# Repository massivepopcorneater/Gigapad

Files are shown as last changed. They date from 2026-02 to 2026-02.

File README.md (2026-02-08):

# Gigapad
A 9-key macropad that includes a LED for each key, a rotary encoder and a 0.91-inch OLED display. I made this project to challenge myself so that I can be better prepared to create real-world solutions and also I having a macropad with an OLED screen and a rotary encoder is pretty cool too. (Also for a soldering iron lol) 

Gigapad is a custom 9-key mechanical macropad built around the Seeed XIAO RP2040, featuring a rotary encoder and an OLED display.  
It is designed as a compact, programmable input device using QMK firmware, suitable for shortcuts, media control, and custom workflows.

---

## 🧱 Case & Assembly Fit

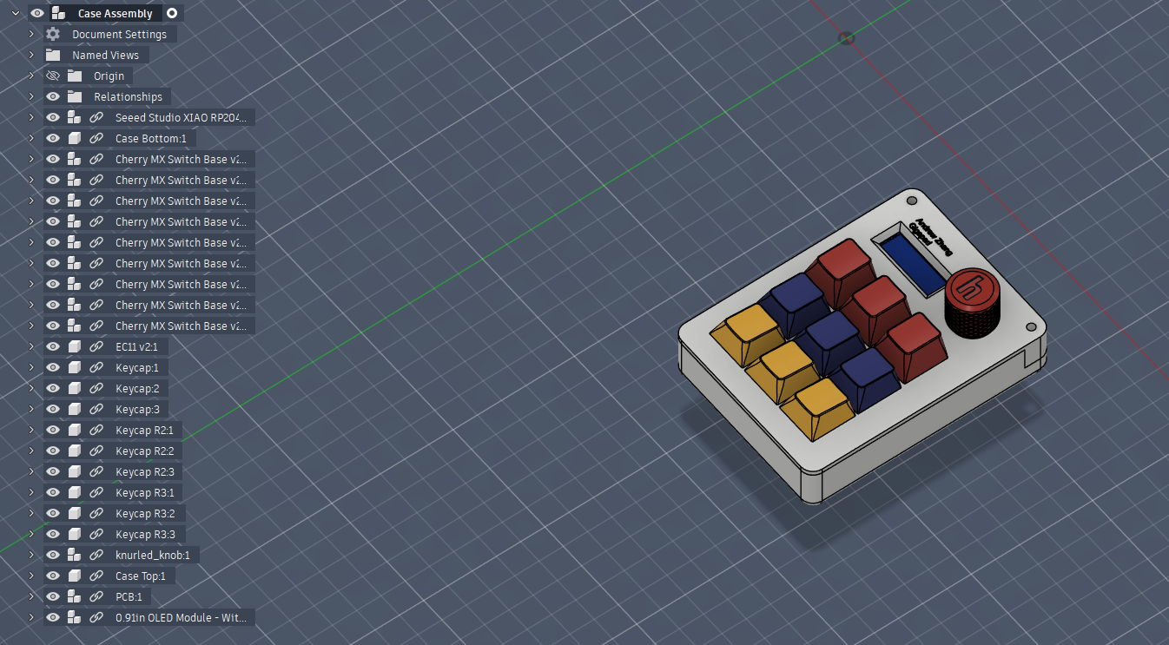
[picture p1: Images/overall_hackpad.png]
Overall Hackpad


Made using Fusion 360 

Features:
- Easy access to the USB-C port
- Secured PCB and case using 4 M3 Screws with brass heatsets (2 on the case, 2 on the case and pcb)
- Different key levels for a more ergonomic feel

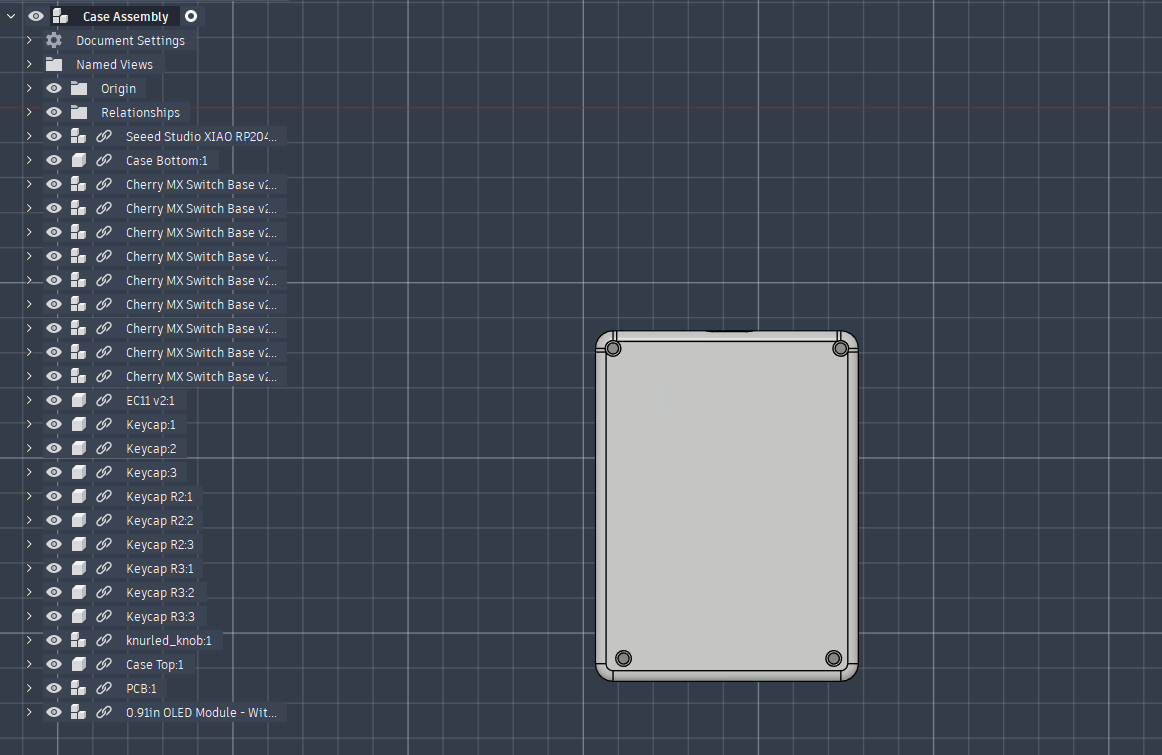
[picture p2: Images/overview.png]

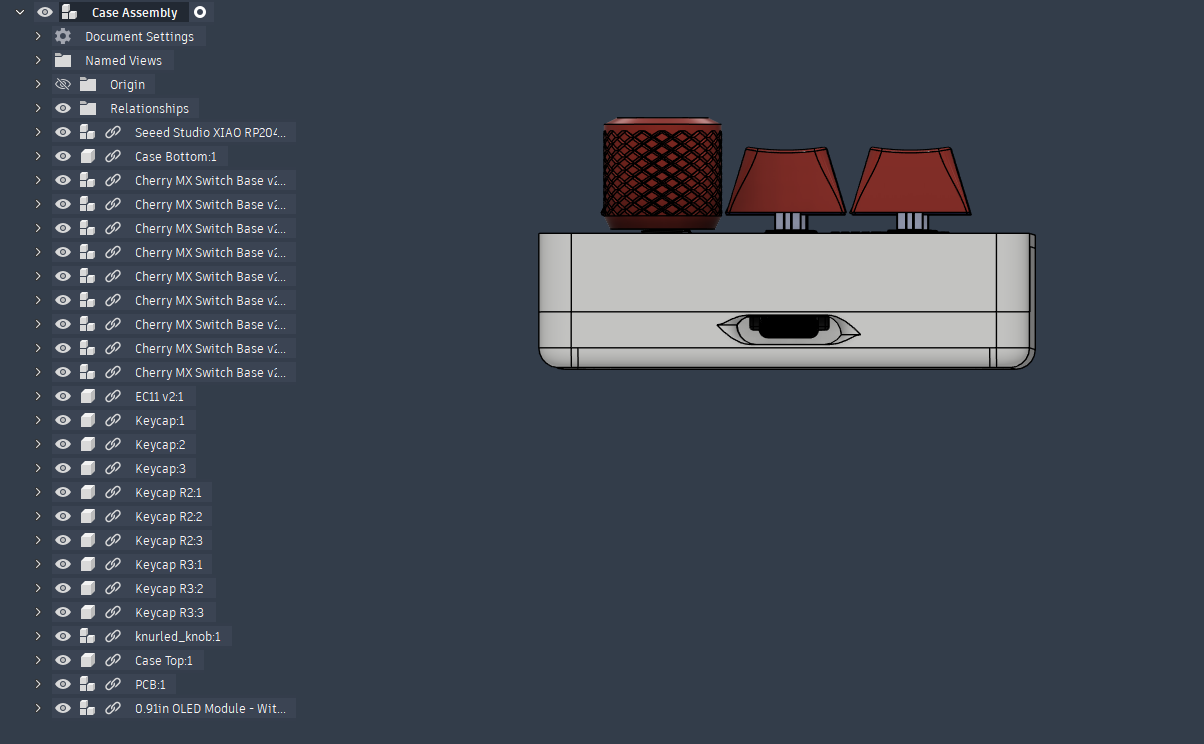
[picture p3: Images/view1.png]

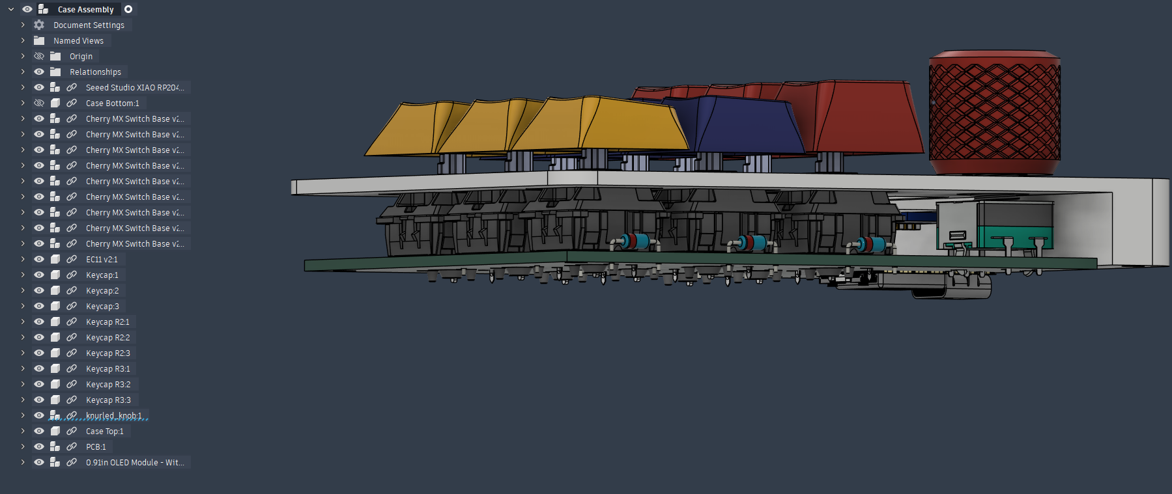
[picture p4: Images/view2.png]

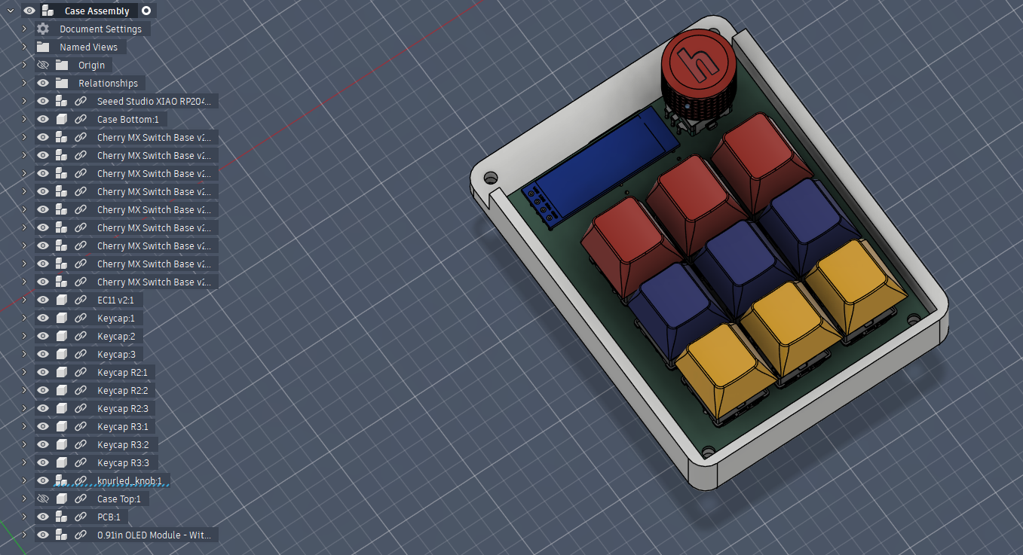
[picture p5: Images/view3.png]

  
---

## 📐 Schematic

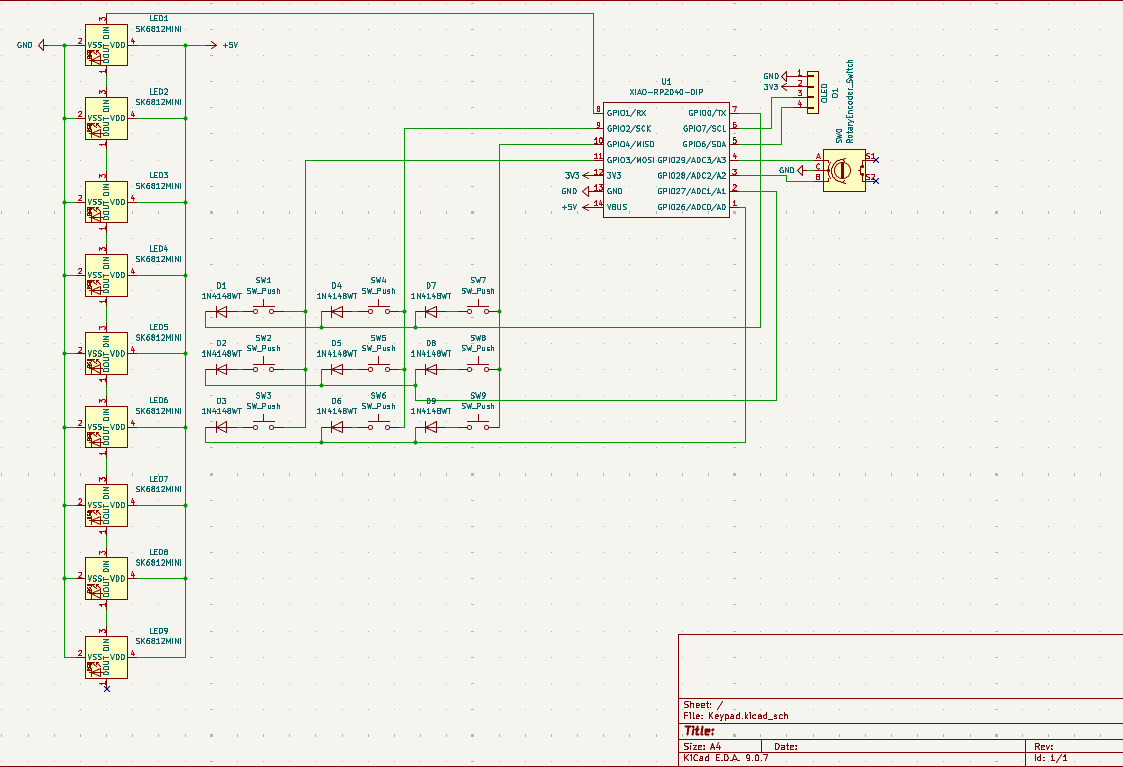
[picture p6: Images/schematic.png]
Schematic


Made Using KiCad

The schematic shows:
- A 3×3 key matrix 
- A rotary encoder connected directly to GPIO pins 
- An OLED display
- 9 Mini-LED in series delivered using parallel power

---

## 🧩 PCB

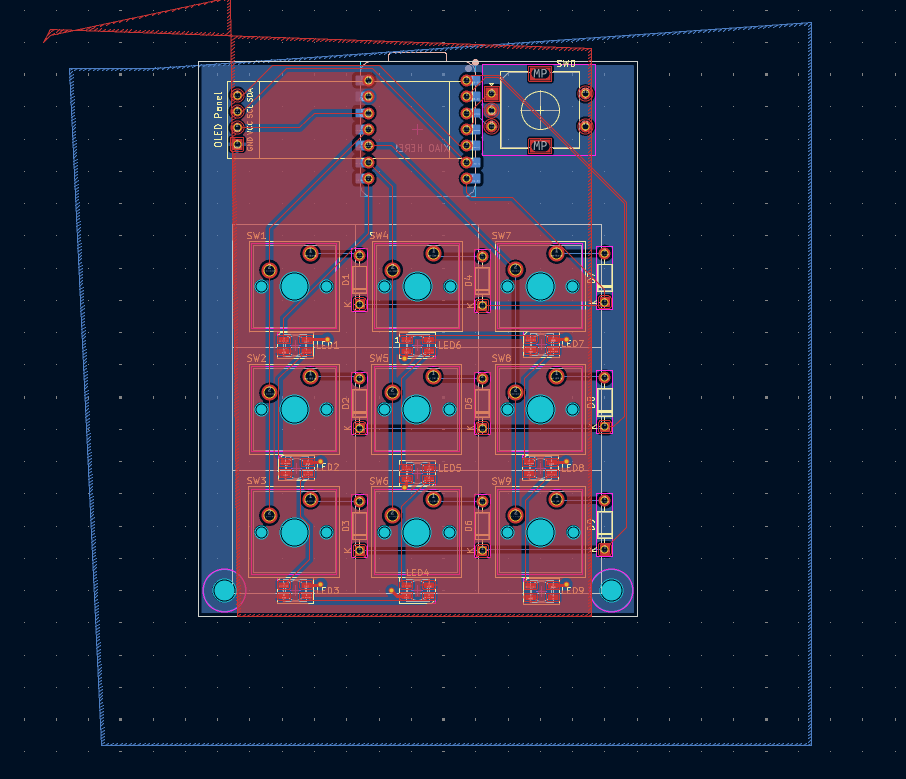
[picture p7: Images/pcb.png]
PCB


The PCB is a 2-layer board designed for JLCPCB manufacturing with:
- 1 oz copper
- Dedicated encoder pins
- Ground pours and 5V pour

---

## 🧾 Bill of Materials (BOM)

| Part | Quantity | Description |
|----|----|----|
| Microcontroller | 1x | Seeed XIAO RP2040 |
| Mechanical Switches | 9x | MX-style switches |
| Keycaps | 9x | ABS Keycaps |
| Rotary Encoder | 1x | EC11 |
| OLED Display | 1x | 0.91-inch OLED Display |
| Diodes | 9x | 1N4148  |
| Brass Heat-Set Inserts | 4x | M3 |
| Screws | 4x | M3 × 16 mm |
| PCB | 1x | Custom 2-layer PCB |
| Case | 1x | 3D-printed enclosure |

---

## 💻 Firmware

Gigapad runs **QMK firmware**, configured for:
- 3×3 key matrix
- Rotary encoder using dedicated GPIO pins
- OLED display output
- Fully customizable keymap

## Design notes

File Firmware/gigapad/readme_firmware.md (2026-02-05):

# gigapad

gigapad

*A short description of the keyboard/project*

* Keyboard Maintainer: [Andrew](https://github.com/massivepopcorneater)
* Hardware Supported: *The PCBs, controllers supported*
* Hardware Availability: *Links to where you can find this hardware*

Make example for this keyboard (after setting up your build environment):

    make gigapad:default

Flashing example for this keyboard:

    make gigapad:default:flash

See the [build environment setup](https://docs.qmk.fm/#/getting_started_build_tools) and the [make instructions](https://docs.qmk.fm/#/getting_started_make_guide) for more information. Brand new to QMK? Start with our [Complete Newbs Guide](https://docs.qmk.fm/#/newbs).

## Bootloader

Enter the bootloader in 3 ways:

* **Bootmagic reset**: Hold down the key at (0,0) in the matrix (usually the top left key or Escape) and plug in the keyboard
* **Physical reset button**: Briefly press the button on the back of the PCB - some may have pads you must short instead
* **Keycode in layout**: Press the key mapped to `QK_BOOT` if it is available

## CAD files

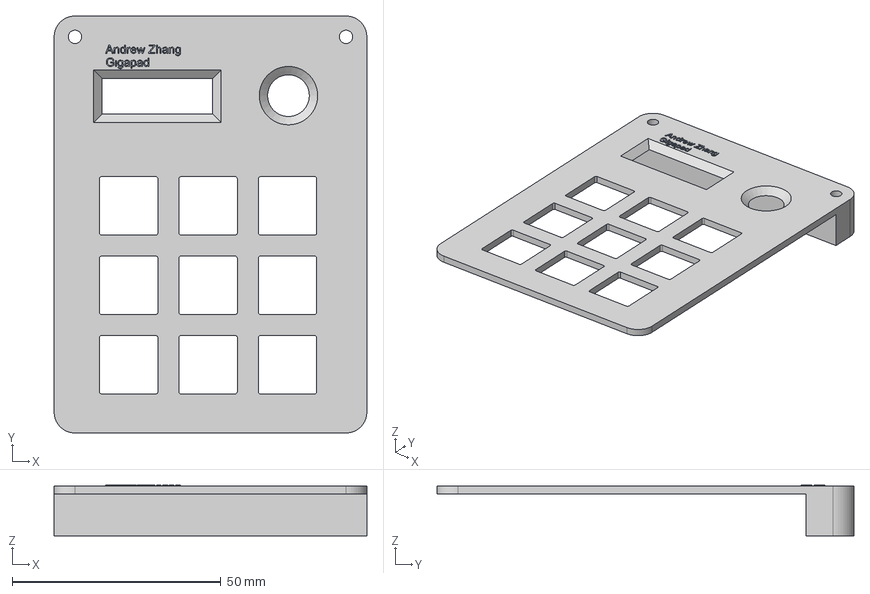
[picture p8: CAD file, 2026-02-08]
Case Design/Case Top.step
75.0 x 100.0 x 12.2 mm

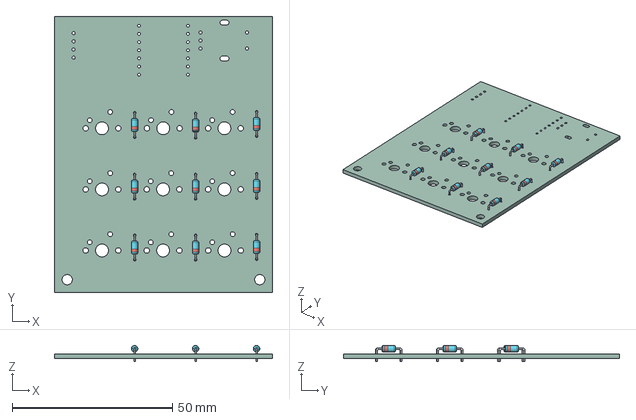
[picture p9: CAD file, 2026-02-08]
Production Files/PCB.step
68.0 x 86.0 x 5.01 mm
D_DO-35_SOD27_P7.62mm_Horizontal x 9
Keypad_PCB

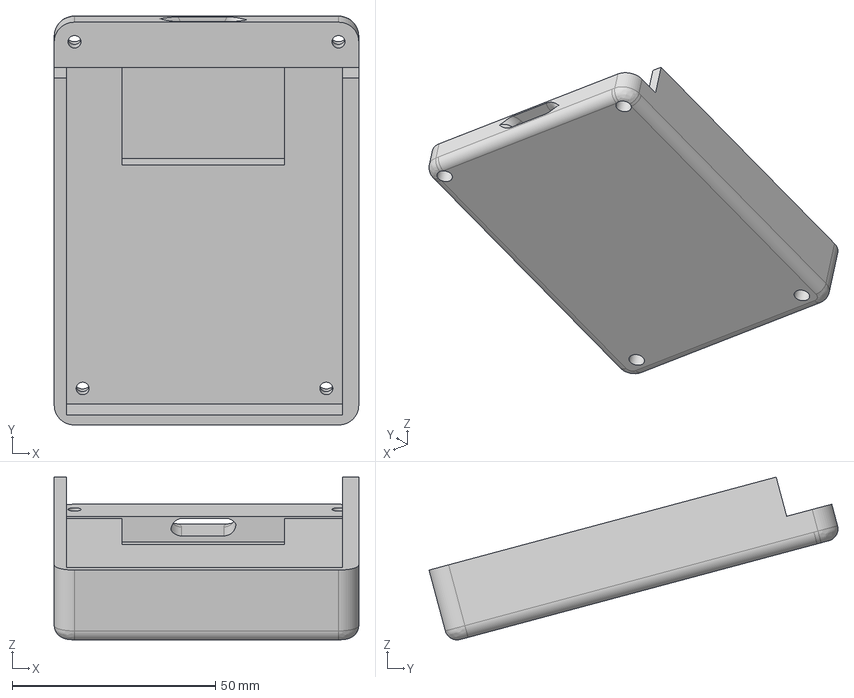
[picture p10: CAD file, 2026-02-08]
Case Design/Case Bottom.step
75.0 x 100.7 x 40.1 mm

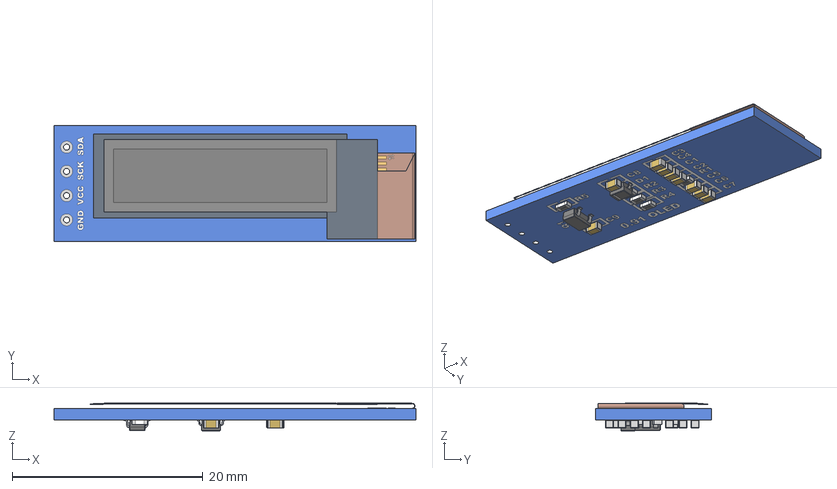
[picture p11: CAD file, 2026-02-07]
Case Design/0.91in OLED Module - Without Glass v1.step
37.9 x 12.1 x 2.93 mm

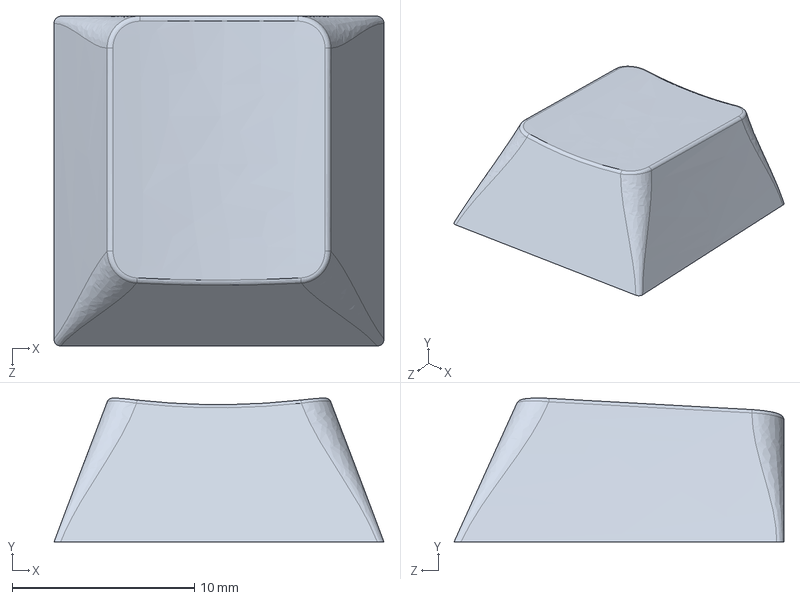
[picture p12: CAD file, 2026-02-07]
Production Files/r2_100.STEP
18.1 x 7.89 x 18.1 mm

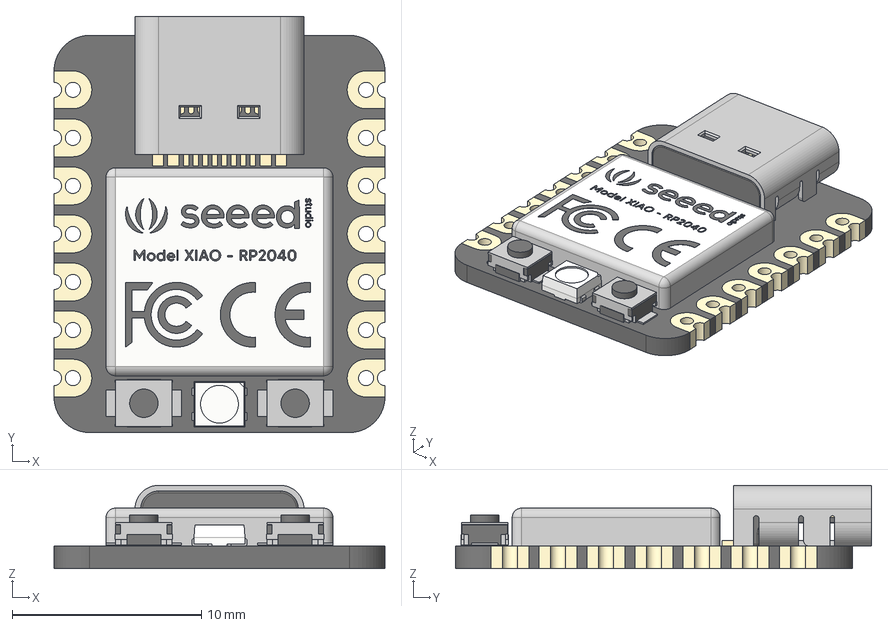
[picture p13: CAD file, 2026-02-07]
Case Design/Seeed Studio XIAO RP2040 v1.step
17.5 x 22.0 x 4.40 mm

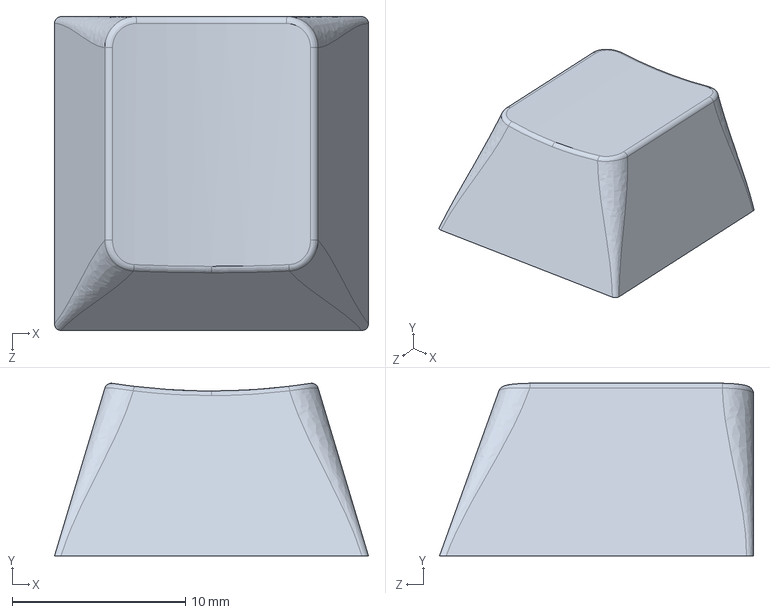
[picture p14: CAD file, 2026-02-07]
Production Files/r1_100.STEP
18.1 x 9.95 x 18.1 mm

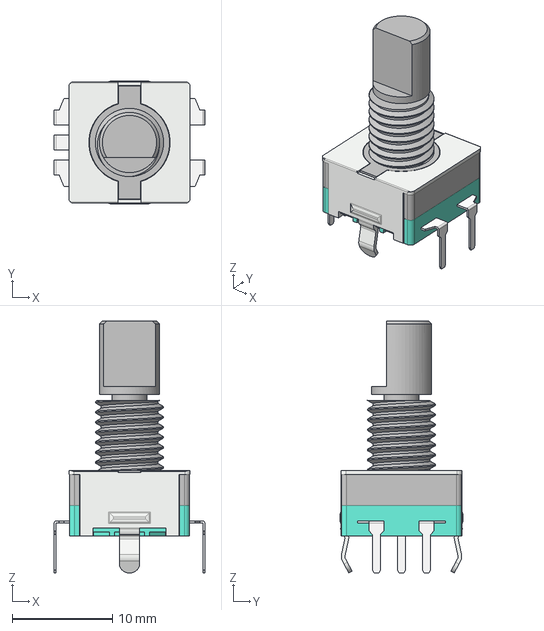
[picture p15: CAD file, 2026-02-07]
Case Design/EC11 v2.step
15.0 x 12.3 x 25.1 mm

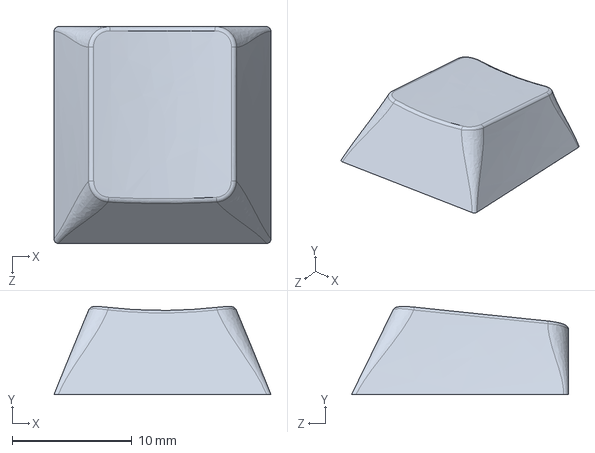
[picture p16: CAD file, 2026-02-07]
Production Files/r3_100.STEP
18.1 x 7.34 x 18.1 mm

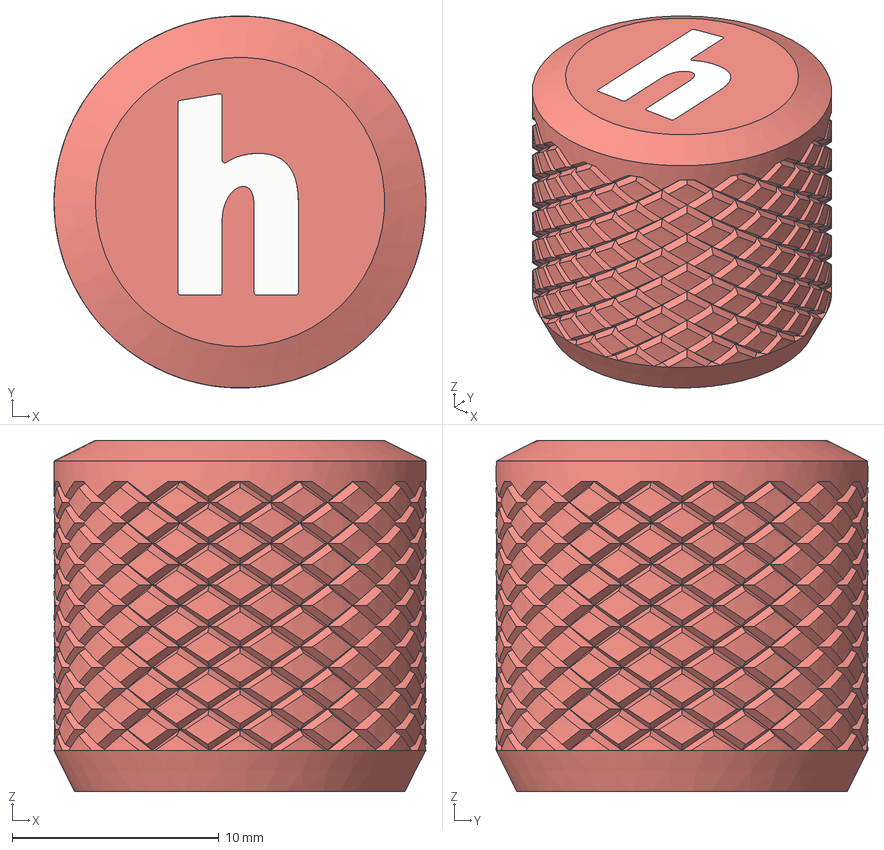
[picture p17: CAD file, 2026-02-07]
Case Design/knurled_knob.step
18.0 x 18.0 x 17.0 mm
Base
H

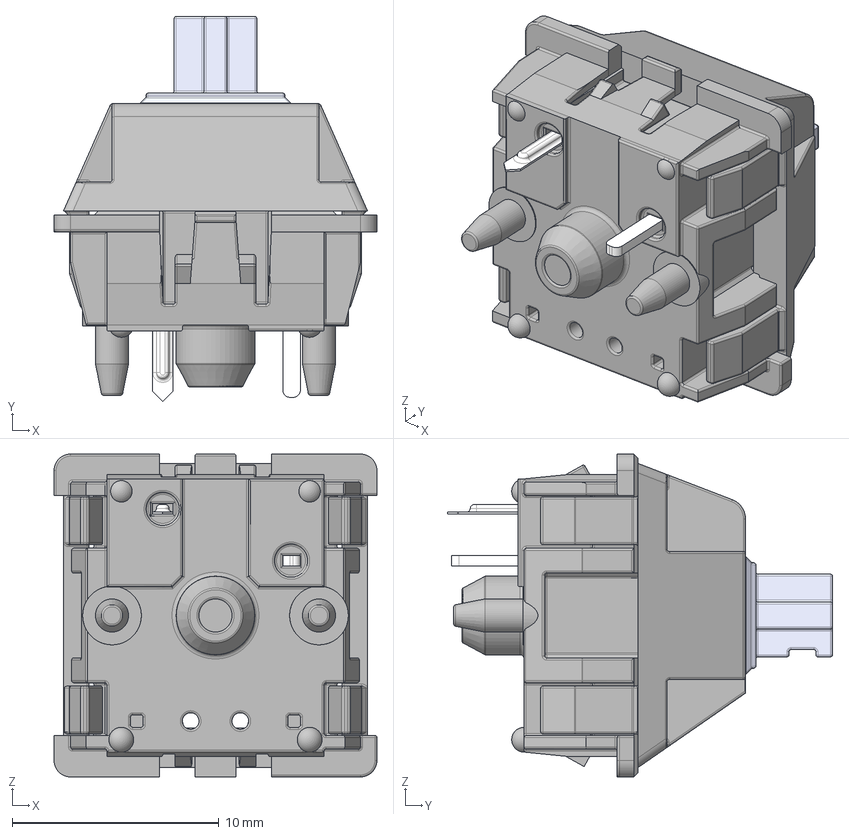
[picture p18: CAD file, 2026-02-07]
Case Design/Cherry MX Switch Base v2.step
15.6 x 18.6 x 15.6 mm

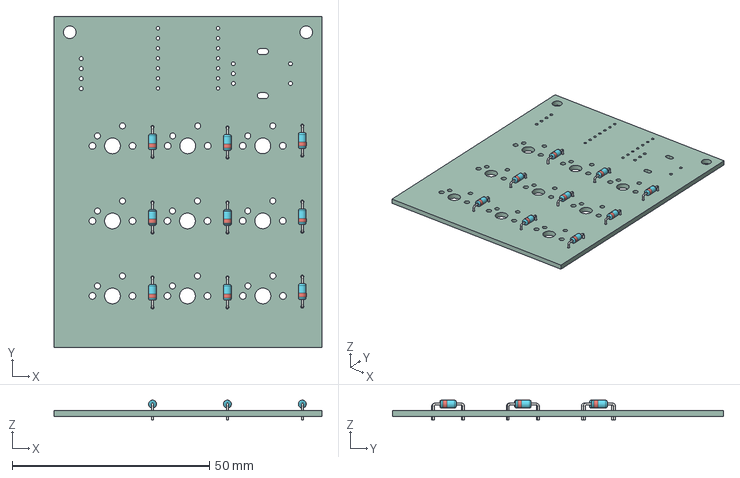
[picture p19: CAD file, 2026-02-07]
Case Design/Keypad.step
68.0 x 84.0 x 5.01 mm
D_DO-35_SOD27_P7.62mm_Horizontal x 9
Keypad_PCB

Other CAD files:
Case Design/Fusion Files/0.91in OLED Module - Without Glass v1.f3d
Case Design/Fusion Files/Case Bottom.f3d
Case Design/Fusion Files/Case Top.f3d
Case Design/Fusion Files/Cherry MX Switch Base v2 (2).f3d
Case Design/Fusion Files/EC11 v2.f3d
Case Design/Fusion Files/M3x12 SHCS v1.f3d

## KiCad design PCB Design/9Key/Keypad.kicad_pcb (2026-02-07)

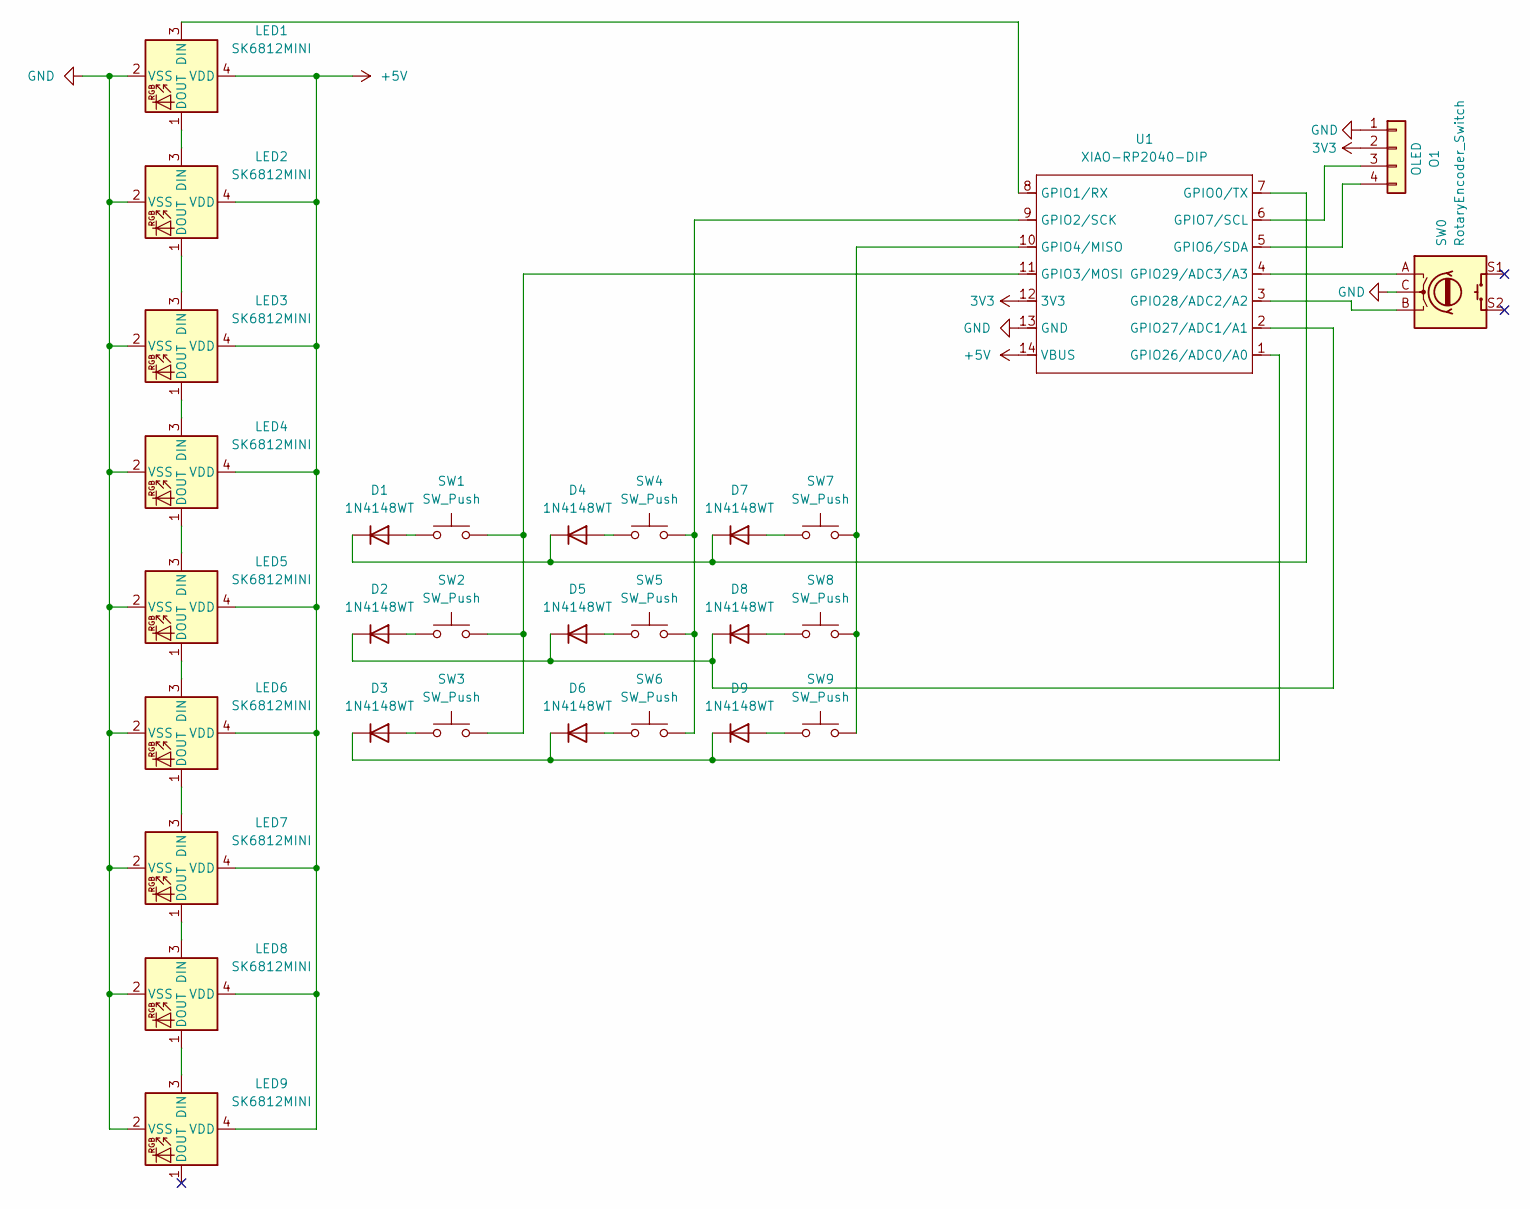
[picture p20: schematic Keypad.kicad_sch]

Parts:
D1, D2, D3, D4, D5, D6, D7, D8, D9: 1N4148WT; D_DO-35_SOD27_P7.62mm_Horizontal
LED1, LED2, LED3, LED4, LED5, LED6, LED7, LED8, LED9: SK6812MINI; LED_SK6812MINI_PLCC4_3.5x3.5mm_P1.75mm
O1: OLED; SSD1306-0.91-OLED-4pin-128x32
SW0: RotaryEncoder_Switch; RotaryEncoder_Alps_EC11E-Switch_Vertical_H20mm
SW1, SW2, SW3, SW4, SW5, SW6, SW7, SW8, SW9: SW_Push; SW_Cherry_MX_1.00u_PCB
U1: XIAO-RP2040-DIP

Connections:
3V3: O1.2, U1.12 (3V3)
+5V: LED1.4 (VDD), LED2.4 (VDD), LED3.4 (VDD), LED4.4 (VDD), LED5.4 (VDD), LED6.4 (VDD), LED7.4 (VDD), LED8.4 (VDD), LED9.4 (VDD), U1.14 (VBUS)
GND: LED1.2 (VSS), LED2.2 (VSS), LED3.2 (VSS), LED4.2 (VSS), LED5.2 (VSS), LED6.2 (VSS), LED7.2 (VSS), LED8.2 (VSS), LED9.2 (VSS), O1.1, SW0.C, U1.13 (GND)
unnamed: D1.2 (A), SW1.1
unnamed: D1.1 (K), D4.1 (K), D7.1 (K), U1.7 (GPIO0/TX)
unnamed: D2.2 (A), SW2.1
unnamed: D2.1 (K), D5.1 (K), D8.1 (K), U1.2 (GPIO27/ADC1/A1)
unnamed: D3.2 (A), SW3.1
unnamed: D3.1 (K), D6.1 (K), D9.1 (K), U1.1 (GPIO26/ADC0/A0)
unnamed: D4.2 (A), SW4.1
unnamed: D5.2 (A), SW5.1
unnamed: D6.2 (A), SW6.1
unnamed: D7.2 (A), SW7.1
unnamed: D8.2 (A), SW8.1
unnamed: D9.2 (A), SW9.1
unnamed: LED1.3 (DIN), U1.8 (GPIO1/RX)
unnamed: LED1.1 (DOUT), LED2.3 (DIN)
unnamed: LED2.1 (DOUT), LED3.3 (DIN)
unnamed: LED3.1 (DOUT), LED4.3 (DIN)
unnamed: LED4.1 (DOUT), LED5.3 (DIN)
unnamed: LED5.1 (DOUT), LED6.3 (DIN)
unnamed: LED6.1 (DOUT), LED7.3 (DIN)
unnamed: LED7.1 (DOUT), LED8.3 (DIN)
unnamed: LED8.1 (DOUT), LED9.3 (DIN)
unnamed: O1.3, U1.6 (GPIO7/SCL)
unnamed: O1.4, U1.5 (GPIO6/SDA)
unnamed: SW4.2, SW5.2, SW6.2, U1.9 (GPIO2/SCK)
unnamed: SW1.2, SW2.2, SW3.2, U1.11 (GPIO3/MOSI)
unnamed: SW7.2, SW8.2, SW9.2, U1.10 (GPIO4/MISO)
unnamed: SW0.B, U1.3 (GPIO28/ADC2/A2)
unnamed: SW0.A, U1.4 (GPIO29/ADC3/A3)

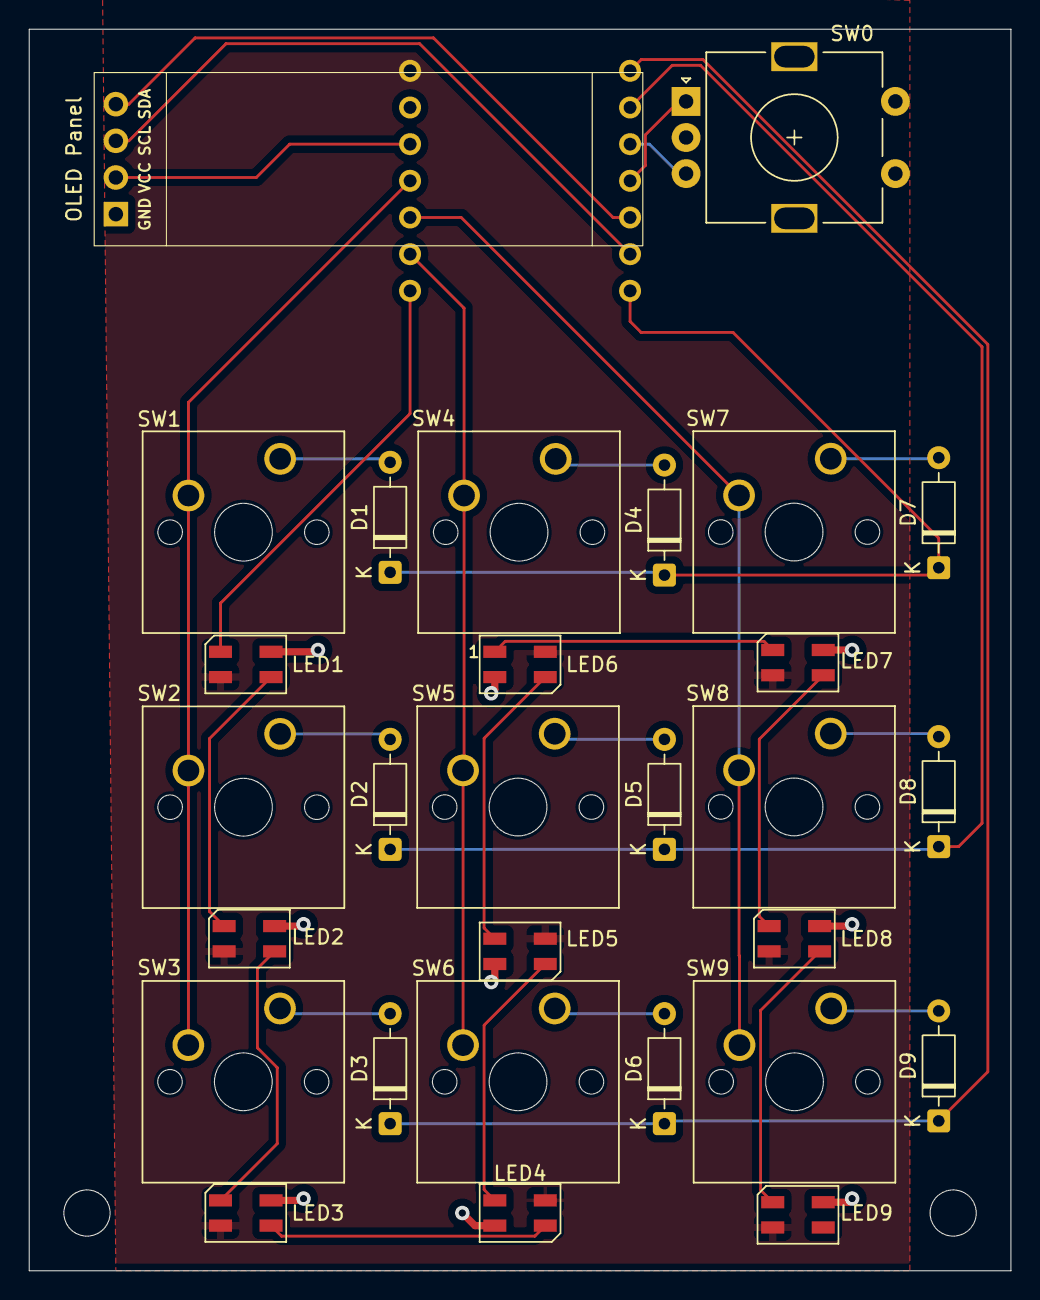
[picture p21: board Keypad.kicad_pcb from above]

Board: 2 copper layers, 68.0 x 86.0 mm, 30 parts (1 on the bottom side), 31 nets.

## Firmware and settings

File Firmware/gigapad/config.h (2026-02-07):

#pragma once

// ===== RGB Matrix (12x SK6812 MINI) =====
#define RGB_DI_PIN GP1
#define RGB_MATRIX_LED_COUNT 9

#define RGB_MATRIX_KEYPRESSES
#define RGB_DISABLE_WHEN_USB_SUSPENDED
#define RGB_MATRIX_MAXIMUM_BRIGHTNESS 180

// ===== Rotary encoder (dedicated pins, not in the key matrix) =====
// From your KiCad PCB: encoder A -> GPIO29 (A3), encoder B -> GPIO28 (A2)
#define ENCODERS_PAD_A { GP29 }
#define ENCODERS_PAD_B { GP28 }

// ===== OLED (SSD1306 over I2C) =====
// From your KiCad PCB: SDA -> GPIO6, SCL -> GPIO7
#define I2C1_SDA_PIN GP6
#define I2C1_SCL_PIN GP7
#define I2C1_CLOCK_SPEED 400000

// Most 0.96\" SSD1306 modules are 128x64; change to OLED_DISPLAY_128X32 if yours is 128x32.
#define OLED_DISPLAY_128X64

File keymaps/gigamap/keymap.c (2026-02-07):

#include QMK_KEYBOARD_H

/*
Hardware (9-key revision, from your KiCad PCB):

- Key matrix: 3x3
  Rows (diode cathodes): GP0, GP27, GP26
  Cols (switch side):    GP2, GP4, GP3

- Rotary encoder (NOT in the matrix):
  A -> GP29 (A3)
  B -> GP28 (A2)

- OLED (SSD1306 over I2C):
  SDA -> GP6, SCL -> GP7
*/

#ifdef ENCODER_ENABLE
bool encoder_update_user(uint8_t index, bool clockwise) {
    if (index != 0) return true;
    if (clockwise) {
        tap_code(KC_VOLU);
    } else {
        tap_code(KC_VOLD);
    }
    return false;
}
#endif

#ifdef OLED_ENABLE
static void render_oled(void) {
    oled_clear();
    oled_set_cursor(0, 0);
    oled_write_ln(PSTR("Gigapad"), false);
    oled_write_ln(PSTR("9-key + enc"), false);
    oled_write_ln(PSTR("Vol: turn knob"), false);
}

bool oled_task_user(void) {
    render_oled();
    return false;
}
#endif

const uint16_t PROGMEM keymaps[][MATRIX_ROWS][MATRIX_COLS] = {
    [0] = LAYOUT(
        KC_P7, KC_P8, KC_P9,
        KC_P4, KC_P5, KC_P6,
        KC_P1, KC_P2, KC_P3
    )
};

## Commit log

2026-02-05 File Name Change
    [Keypad-B_Cu.gbr, Keypad-B_Mask.gbr, Keypad-B_Paste.gbr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]
2026-02-05 adding parts
    [0.91in OLED Module - Without Glass v1.f3d, Cherry MX Switch Base v2 (2).f3d, EC11 v2.f3d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]
2026-02-07 New PCB Format
    [Keypad-B_Cu.gbr, Keypad-B_Mask.gbr, Keypad-B_Paste.gbr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]
2026-02-08 revision update
    [0.91in OLED Module - Without Glass v1.f3d, Case Bottom.f3d, Case Top.f3d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]
2026-02-16 schematic clean up
    [Keypad.kicad_sch]
